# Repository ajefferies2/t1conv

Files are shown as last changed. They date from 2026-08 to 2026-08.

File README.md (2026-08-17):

# t1conv

Current Progress: Finished schematics, workinf on layout
100BASE-T1 ↔ 100BASE-TX media converter + dual CAN FD/USB adapter on one
board.

## Features

- Wire-speed T1↔TX conversion, PHY-to-PHY (DP83TC811 ↔ DP83822 over RGMII).
  No MAC, no firmware in the data path, converts with the MCU in reset.
- Two independent CAN FD channels over USB, using the gs_usb protocol:
  works out of the box with SocketCAN, python-can, and SavvyCAN.
- Software-switchable termination on each CAN channel (PhotoMOS; for example,
  `ip link set can0 type can termination 120`).
- Software-selectable T1 master/slave: FET on the strap pin, resampled by
  PHY reset. Boards are identical; role is a console command.
- Powered and flashed over USB-C. Blank MCU enumerates in DFU; BOOT button
  for recovery; SWD pads as last resort.

## Info

- Transformerless T1 MDI: TI-validated CMC, CM termination matched to that
  specific choke, 2 kV coupling network, 100 Ω differential on both MDI sides.
- Back-to-back RGMII delay budget: 25 MHz SDR at 100M, TX+RX internal delay
  strapped in the T1 PHY, strap tables derived from SNLA292/SNLU231.

## Schematics

The images below are exported from the current KiCad hierarchy.

### Top level

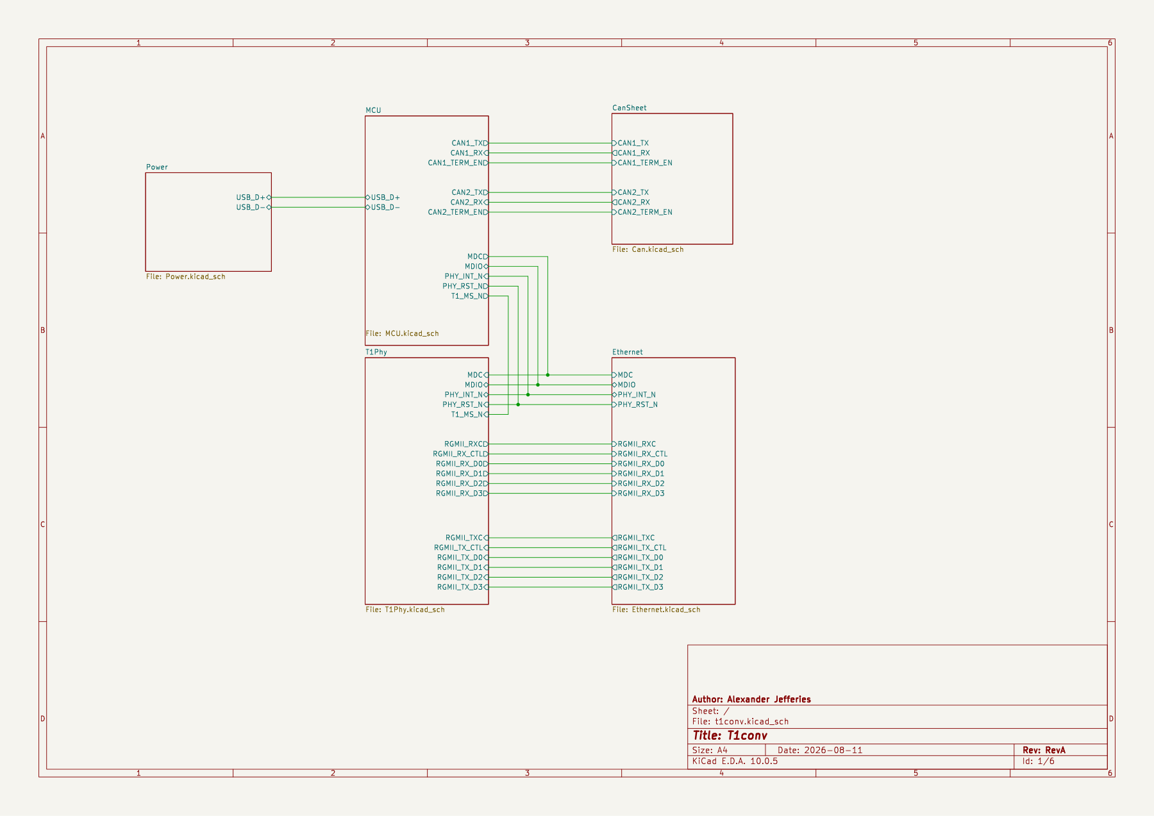
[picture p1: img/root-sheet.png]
Top-level schematic


### Power

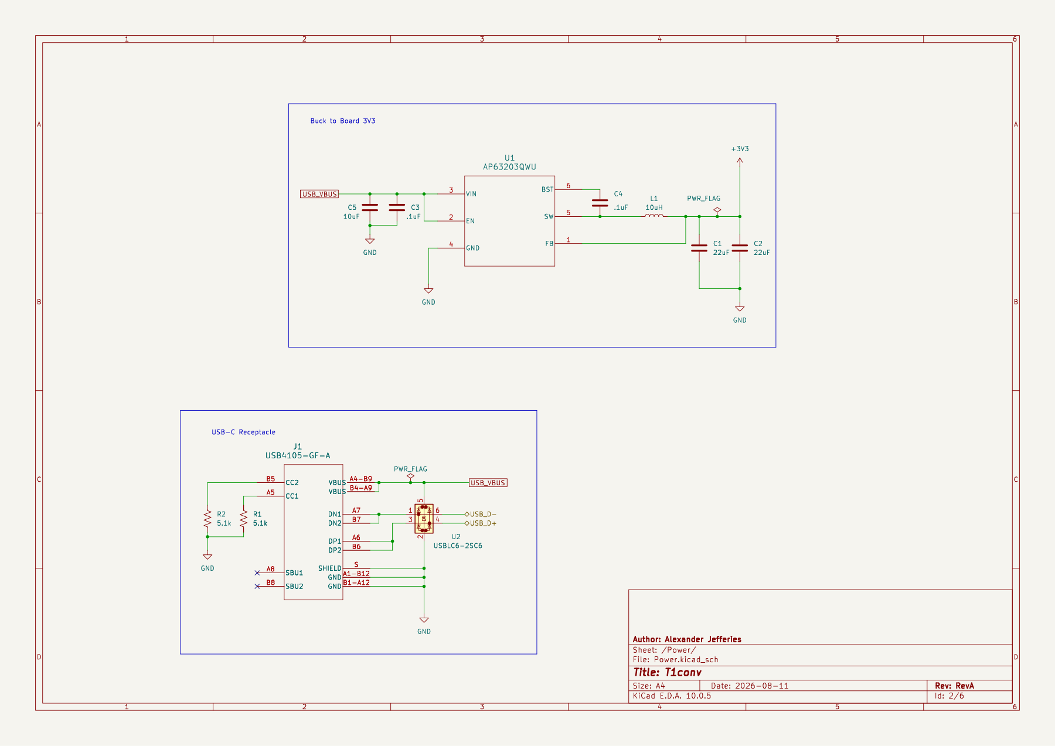
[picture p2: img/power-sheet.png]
Power schematic


### MCU

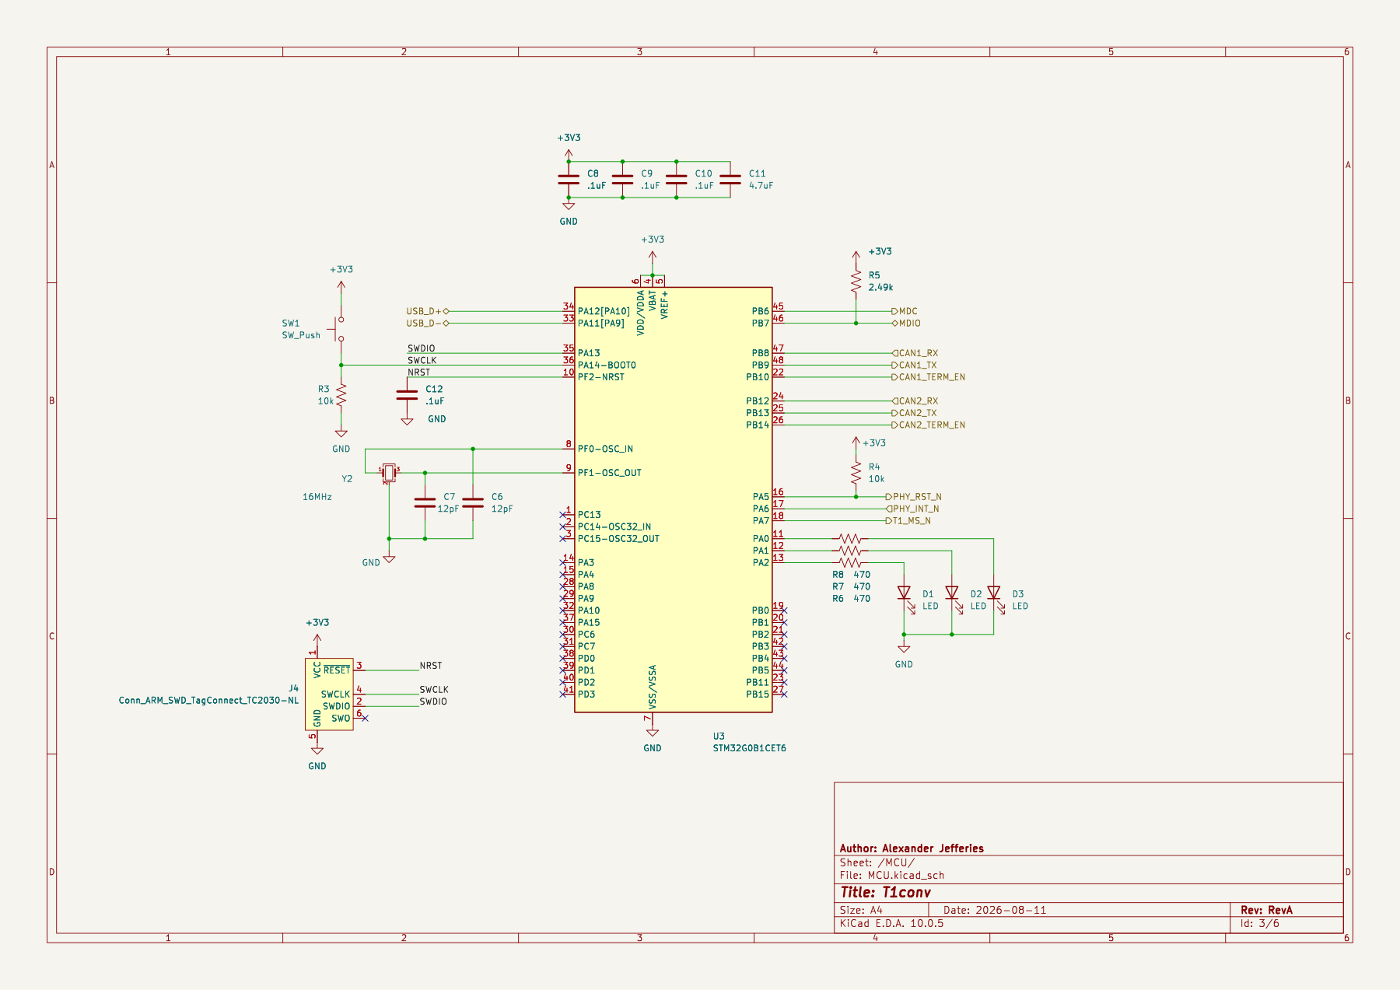
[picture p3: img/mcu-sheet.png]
MCU and USB schematic


### Dual CAN FD

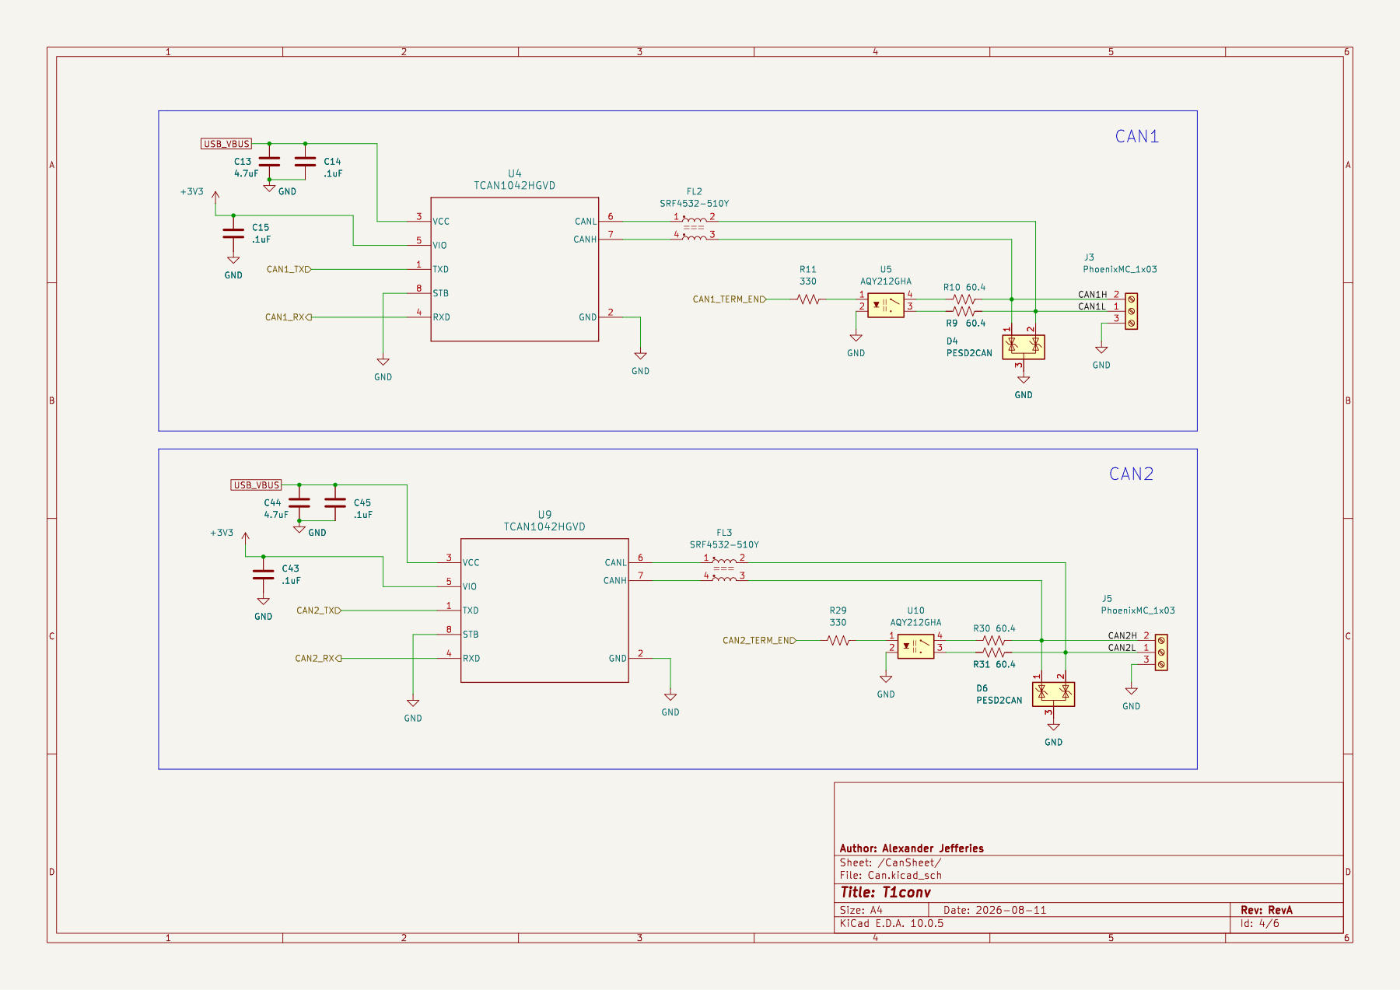
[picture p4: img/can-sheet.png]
Dual CAN FD schematic


### 100BASE-T1 PHY

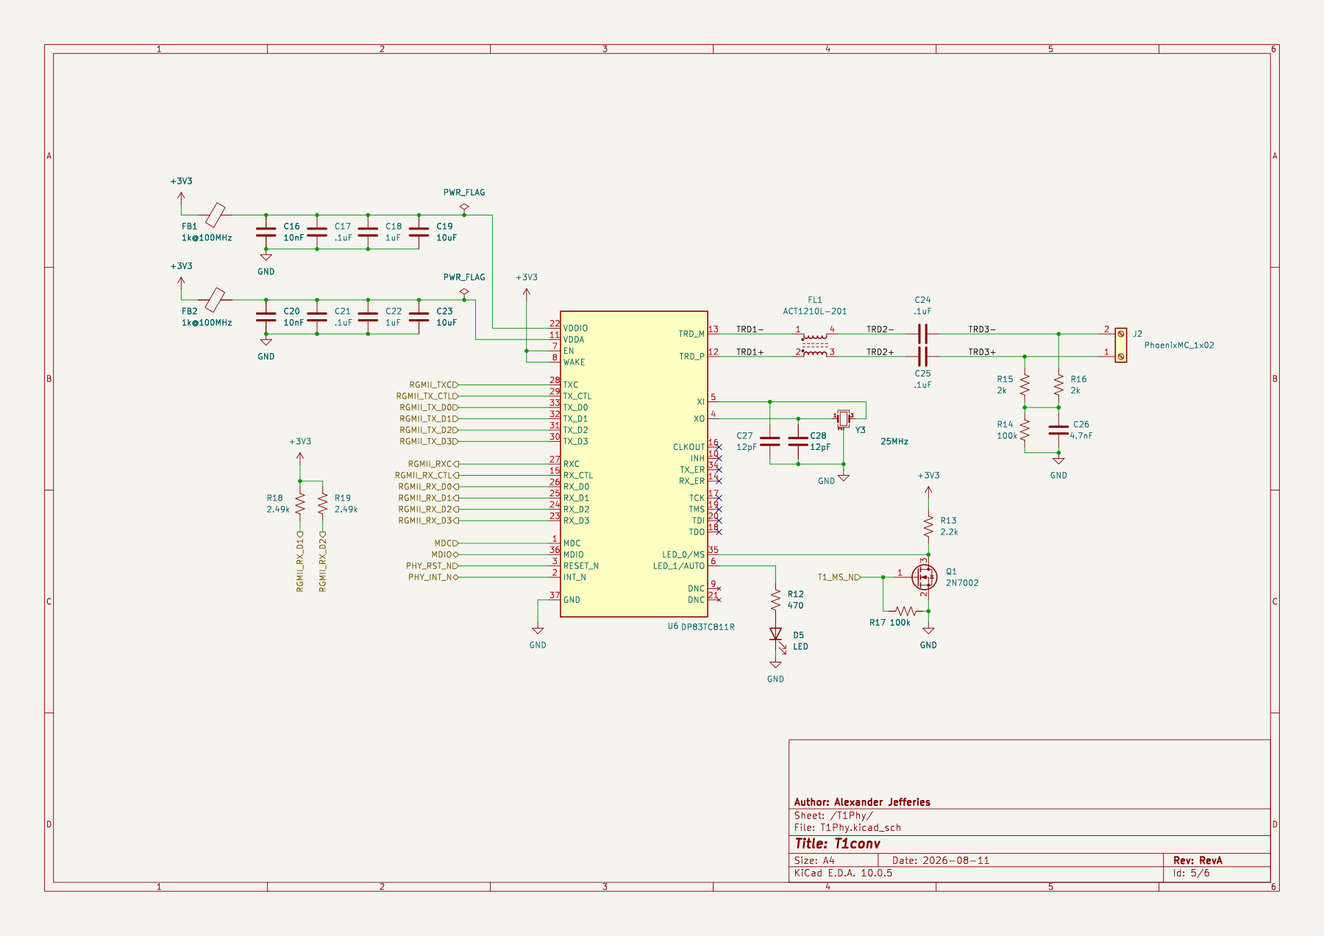
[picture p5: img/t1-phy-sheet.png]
100BASE-T1 PHY schematic


### 100BASE-TX Ethernet PHY

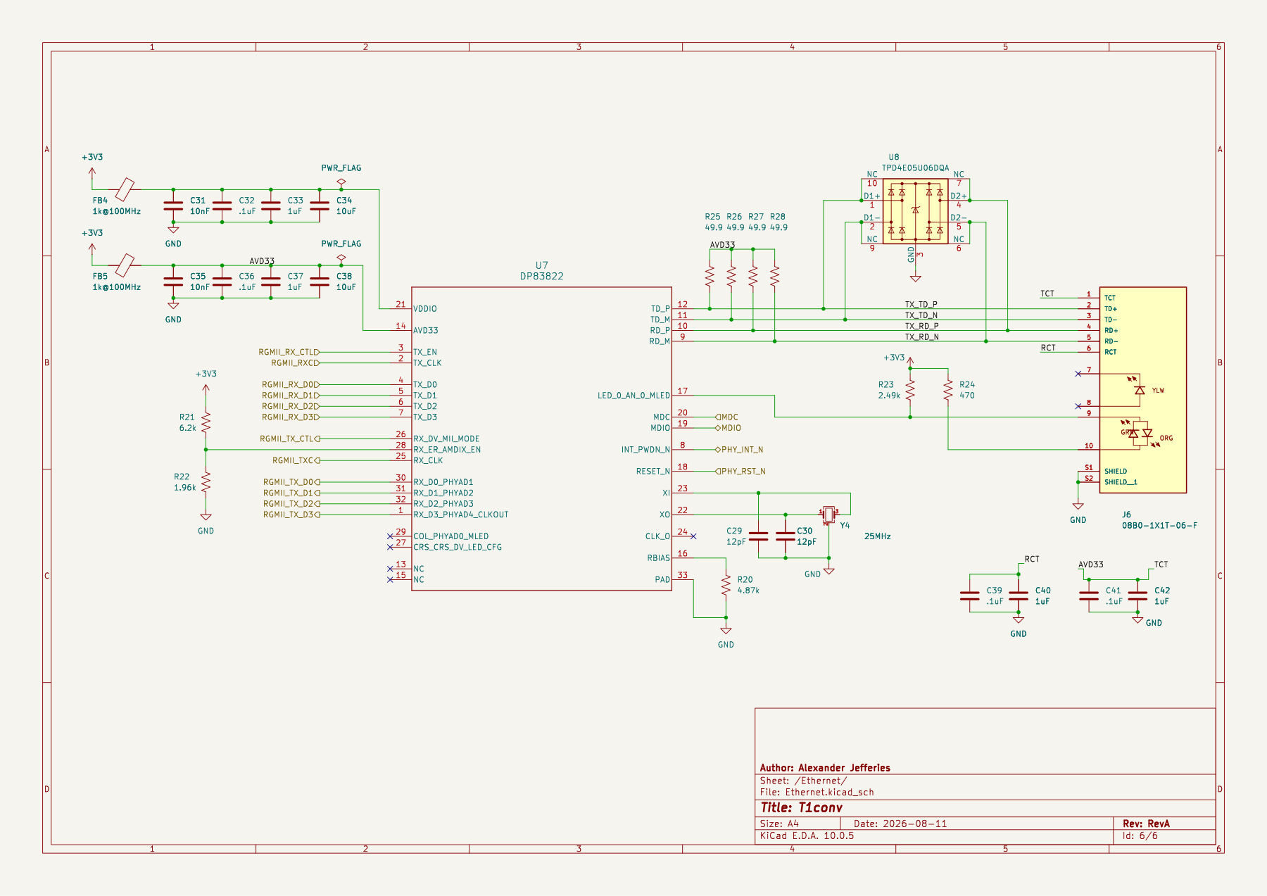
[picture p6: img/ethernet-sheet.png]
100BASE-TX Ethernet PHY schematic


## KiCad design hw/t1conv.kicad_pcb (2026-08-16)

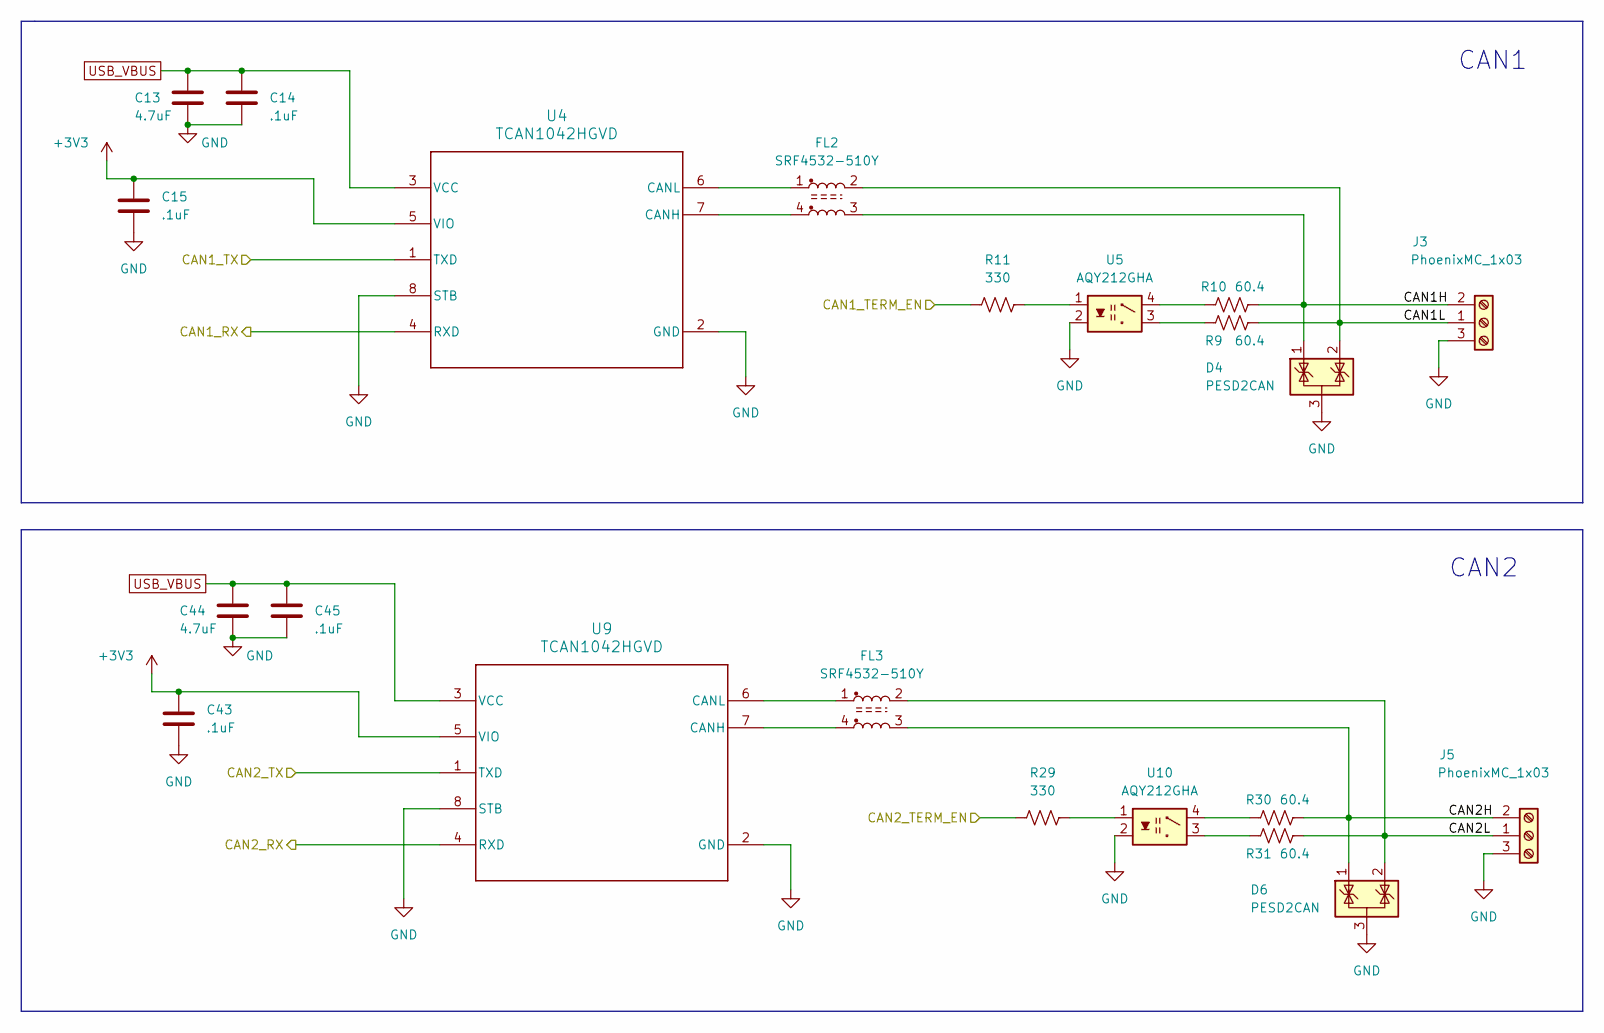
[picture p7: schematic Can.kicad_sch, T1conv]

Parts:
C13, C44: 4.7uF; C_0603_1608Metric
C14, C15, C43, C45: .1uF; C_0603_1608Metric
D4, D6: PESD2CAN; SOT-23; MPN PESD2CAN,215; DigiKey 1727-3891-1-ND
FL2, FL3: SRF4532-510Y; SRF4532; MPN SRF4532-510Y; LCSC C2651134
J3, J5: PhoenixMC_1x03; PhoenixContact_MC_1,5_3-G-3.5_1x03_P3.50mm_Horizontal; MPN 1803581
R9, R10, R30, R31: 60.4; R_0603_1608Metric
R11, R29: 330; R_0603_1608Metric
U4, U9: TCAN1042HGVD; TCAN1042_VSON8; MPN TCAN1042HGVD; DigiKey 296-TCAN1042HGVDR-ND
U5, U10: AQY212GHA; MPN AQY212GHAX; DigiKey 255-6063-1-ND

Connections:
+3V3: C15.1, C43.1, U4.5 (VIO), U9.5 (VIO); also elsewhere on the board
/CanSheet/CAN1H: D4.1 (K), FL2.3, J3.2, R10.2
/CanSheet/CAN1L: D4.2 (K), FL2.2, J3.1, R9.2
/CanSheet/CAN1_RX: U4.4 (RXD); also elsewhere on the board
/CanSheet/CAN1_TERM_EN: R11.2; also elsewhere on the board
/CanSheet/CAN1_TX: U4.1 (TXD); also elsewhere on the board
/CanSheet/CAN2H: D6.1 (K), FL3.3, J5.2, R30.2
/CanSheet/CAN2L: D6.2 (K), FL3.2, J5.1, R31.2
/CanSheet/CAN2_RX: U9.4 (RXD); also elsewhere on the board
/CanSheet/CAN2_TERM_EN: R29.2; also elsewhere on the board
/CanSheet/CAN2_TX: U9.1 (TXD); also elsewhere on the board
GND: C13.2, C14.2, C15.2, C43.2, C44.2, C45.2, D4.3 (A), D6.3 (A), J3.3, J5.3, U4.2 (GND), U4.8 (STB), U5.2, U9.2 (GND), U9.8 (STB), U10.2; also elsewhere on the board
unnamed: R9.1, U5.3
unnamed: R10.1, U5.4
unnamed: R11.1, U5.1
unnamed: R29.1, U10.1
unnamed: R30.1, U10.4
unnamed: R31.1, U10.3
unnamed: FL2.4, U4.7 (CANH)
unnamed: FL2.1, U4.6 (CANL)
unnamed: FL3.4, U9.7 (CANH)
unnamed: FL3.1, U9.6 (CANL)
USB_VBUS: C13.1, C14.1, C44.1, C45.1, U4.3 (VCC), U9.3 (VCC); also elsewhere on the board

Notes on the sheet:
CAN2
CAN1

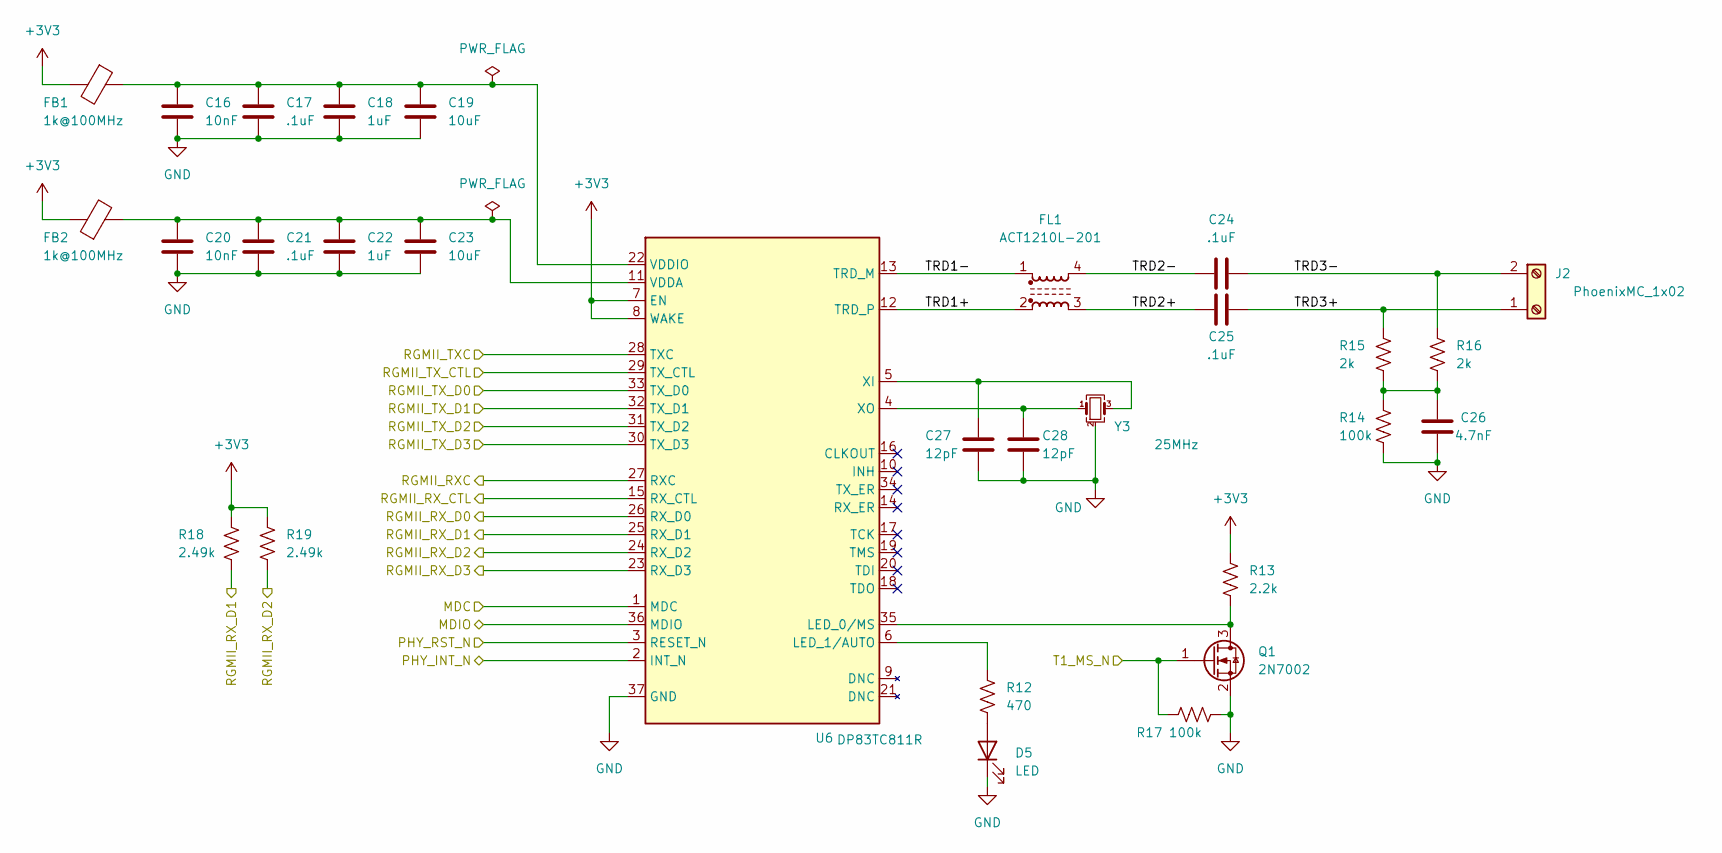
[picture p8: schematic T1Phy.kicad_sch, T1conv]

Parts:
C16, C20: 10nF; C_0603_1608Metric
C17, C21, C24, C25: .1uF; C_0603_1608Metric
C18, C22: 1uF; C_0603_1608Metric
C19, C23: 10uF; C_0603_1608Metric
C26: 4.7nF; C_0603_1608Metric
C27, C28: 12pF; C_0603_1608Metric
D5: LED; LED_0603_1608Metric
FB1, FB2: 1k@100MHz; R_0805_2012Metric; MPN house-brand basic tier - pick at sweep 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
FL1: ACT1210L-201; ACT1210L_3225; MPN ACT1210L-201-2P-TL00; DigiKey 445-ACT1210L-201-2P-TL00CT-ND
J2: PhoenixMC_1x02; PhoenixContact_MC_1,5_2-G-3.5_1x02_P3.50mm_Horizontal; MPN 1803578
Q1: 2N7002; SOT-23; MPN 2N7002; LCSC C8545
R12: 470; R_0603_1608Metric
R13: 2.2k; R_0603_1608Metric
R14, R17: 100k; R_0603_1608Metric
R15, R16: 2k; R_0603_1608Metric
R18, R19: 2.49k; R_0603_1608Metric
U6: DP83TC811R; DP83TC811R_RND0036A; MPN DP83TC811RWRNDRQ1; DigiKey 296-DP83TC811RWRNDRQ1-ND
Y3: 25MHz; Crystal_SMD_3225-4Pin_3.2x2.5mm

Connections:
+3V3: FB1.2, FB2.1, R13.1, R18.1, R19.1, U6.7 (EN), U6.8 (WAKE); also elsewhere on the board
/Ethernet/MDC: U6.1 (MDC); also elsewhere on the board
/Ethernet/MDIO: U6.36 (MDIO); also elsewhere on the board
/Ethernet/PHY_INT_N: U6.2 (INT_N); also elsewhere on the board
/Ethernet/PHY_RST_N: U6.3 (RESET_N); also elsewhere on the board
/Ethernet/RGMII_RXC: U6.27 (RXC); also elsewhere on the board
/Ethernet/RGMII_RX_CTL: U6.15 (RX_CTL); also elsewhere on the board
/Ethernet/RGMII_RX_D0: U6.26 (RX_D0); also elsewhere on the board
/Ethernet/RGMII_RX_D1: R18.2, U6.25 (RX_D1); also elsewhere on the board
/Ethernet/RGMII_RX_D2: R19.2, U6.24 (RX_D2); also elsewhere on the board
/Ethernet/RGMII_RX_D3: U6.23 (RX_D3); also elsewhere on the board
/Ethernet/RGMII_TXC: U6.28 (TXC); also elsewhere on the board
/Ethernet/RGMII_TX_CTL: U6.29 (TX_CTL); also elsewhere on the board
/Ethernet/RGMII_TX_D0: U6.33 (TX_D0); also elsewhere on the board
/Ethernet/RGMII_TX_D1: U6.32 (TX_D1); also elsewhere on the board
/Ethernet/RGMII_TX_D2: U6.31 (TX_D2); also elsewhere on the board
/Ethernet/RGMII_TX_D3: U6.30 (TX_D3); also elsewhere on the board
/MCU/T1_MS_N: Q1.1 (G), R17.1; also elsewhere on the board
/T1Phy/TRD1+: FL1.2, U6.12 (TRD_P)
/T1Phy/TRD1-: FL1.1, U6.13 (TRD_M)
/T1Phy/TRD2+: C25.2, FL1.3
/T1Phy/TRD2-: C24.1, FL1.4
/T1Phy/TRD3+: C25.1, J2.1, R15.1
/T1Phy/TRD3-: C24.2, J2.2, R16.1
GND: C16.2, C17.2, C18.2, C19.2, C20.2, C21.2, C22.2, C23.2, C26.2, C27.2, C28.2, D5.1 (K), Q1.2 (S), R14.2, R17.2, U6.37 (GND), Y3.2 (G), Y3.4 (G); also elsewhere on the board
unnamed: C26.1, R14.1, R15.2, R16.2
unnamed: D5.2 (A), R12.2
unnamed: Q1.3 (D), R13.2, U6.35 (LED_0/MS)
unnamed: R12.1, U6.6 (LED_1/AUTO)
unnamed: C20.1, C21.1, C22.1, C23.1, FB2.2, U6.11 (VDDA)
unnamed: C16.1, C17.1, C18.1, C19.1, FB1.1, U6.22 (VDDIO)
unnamed: C27.1, U6.5 (XI), Y3.3
unnamed: C28.1, U6.4 (XO), Y3.1

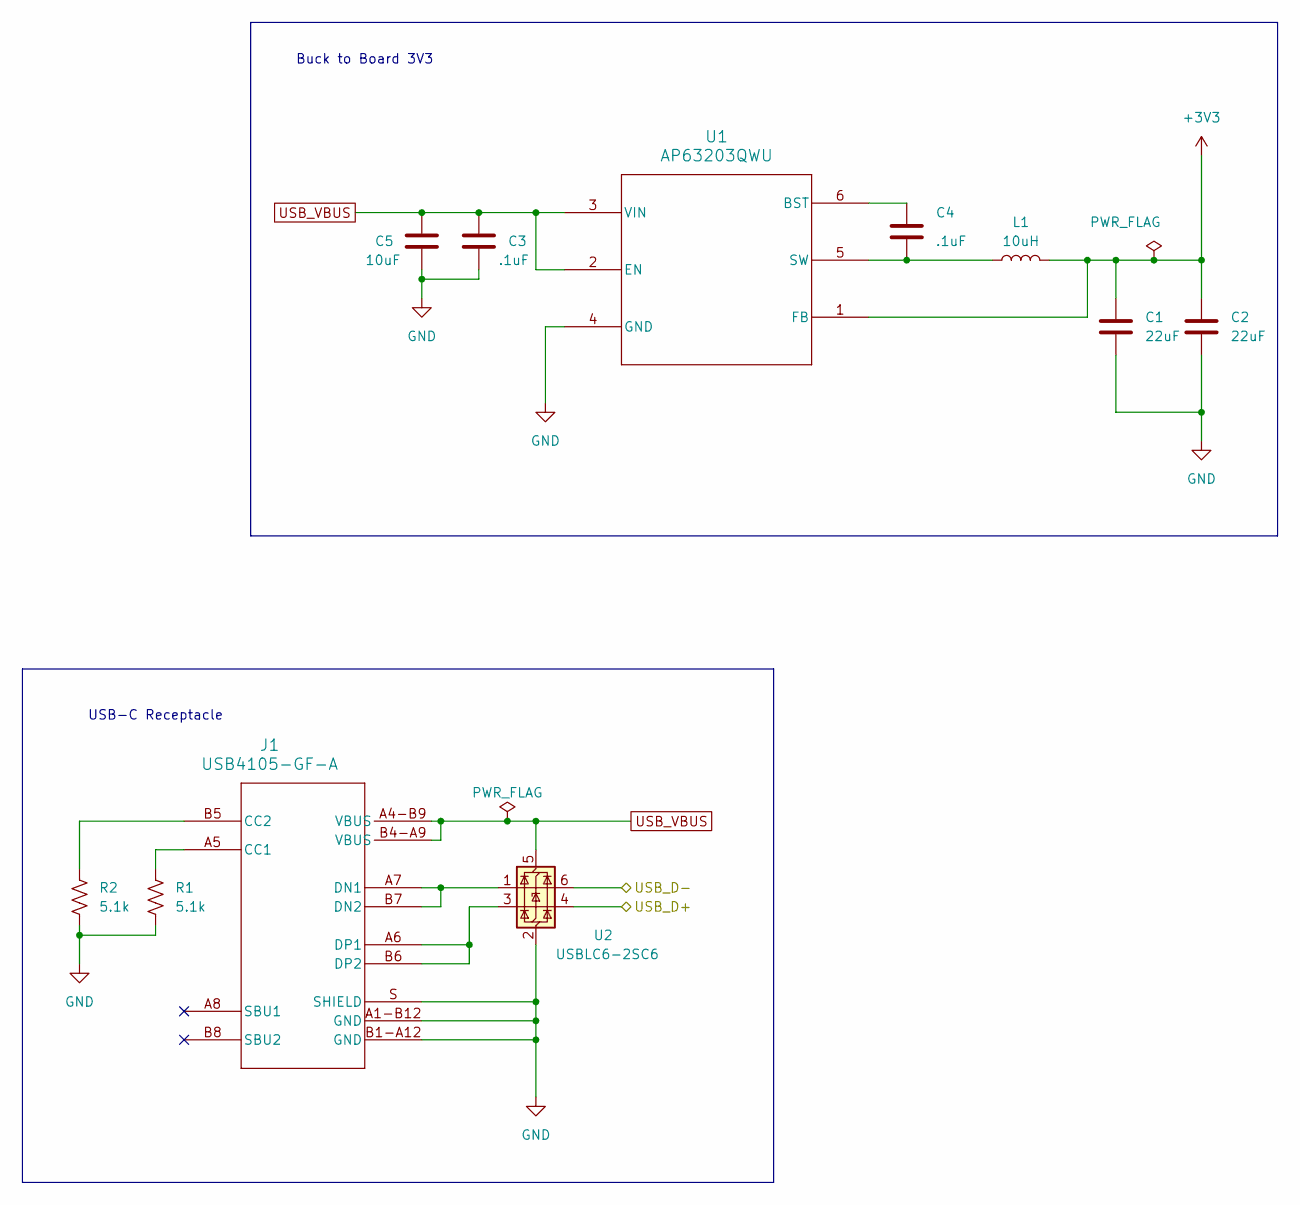
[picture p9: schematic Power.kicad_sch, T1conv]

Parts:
C1, C2: 22uF; C_0603_1608Metric
C3, C4: .1uF; C_0603_1608Metric
C5: 10uF; C_0603_1608Metric
J1: USB4105-GF-A; MPN USB4105-GF-A; DigiKey 2073-USB4105-GF-ACT-ND
L1: 10uH; SWPA5040
R1, R2: 5.1k; R_0603_1608Metric
U1: AP63203QWU; AP63203_TSOT26; MPN AP63203QWU-7; DigiKey AP63203QWU-7DICT-ND
U2: USBLC6-2SC6; SOT-23-6; MPN USBLC6-2SC6; DigiKey 497-5235-1-ND

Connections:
+3V3: C1.1, C2.1, L1.2, U1.1 (FB); also elsewhere on the board
/MCU/USB_D+: U2.4 (I/O2); also elsewhere on the board
/MCU/USB_D-: U2.6 (I/O1); also elsewhere on the board
GND: C1.2, C2.2, C3.2, C5.2, J1.A1-B12 (GND), J1.B1-A12 (GND), J1.S (SHIELD), R1.2, R2.2, U1.4 (GND), U2.2 (GND); also elsewhere on the board
unnamed: J1.A5 (CC1), R1.1
unnamed: J1.B5 (CC2), R2.1
unnamed: J1.A7 (DN1), J1.B7 (DN2), U2.1 (I/O1)
unnamed: J1.A6 (DP1), J1.B6 (DP2), U2.3 (I/O2)
unnamed: C4.1, U1.6 (BST)
unnamed: C4.2, L1.1, U1.5 (SW)
USB_VBUS: C3.1, C5.1, J1.A4-B9 (VBUS), J1.B4-A9 (VBUS), U1.2 (EN), U1.3 (VIN), U2.5 (VBUS); also elsewhere on the board

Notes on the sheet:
USB-C Receptacle
Buck to Board 3V3

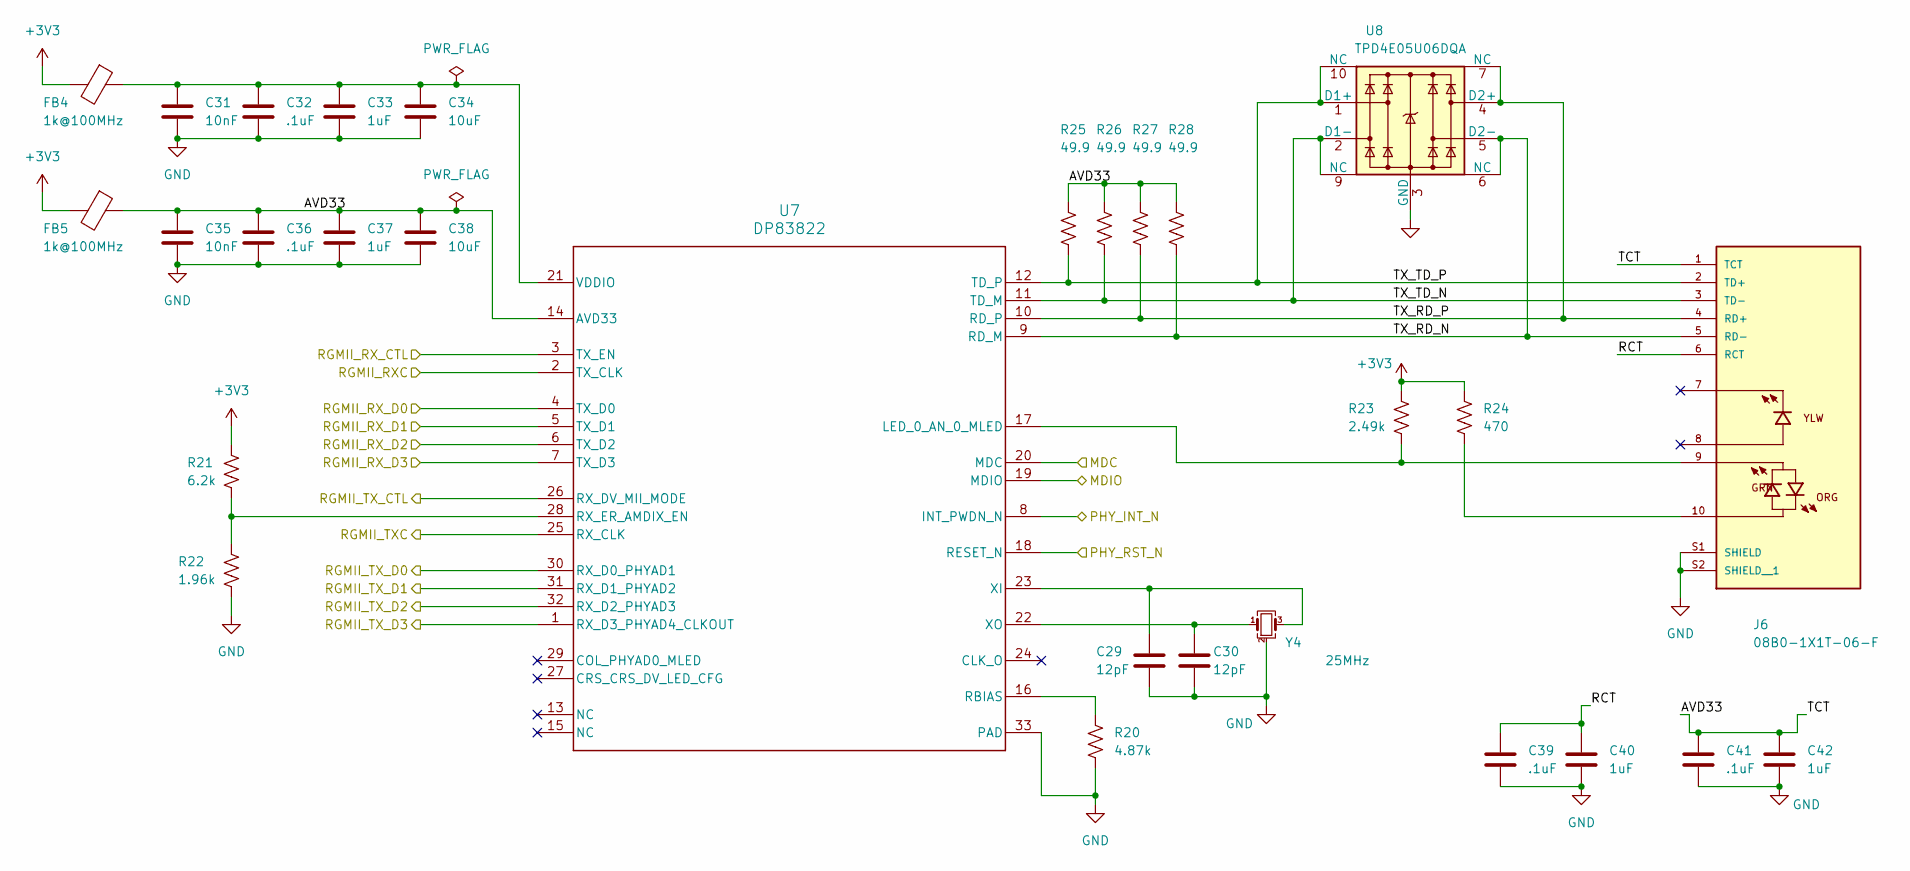
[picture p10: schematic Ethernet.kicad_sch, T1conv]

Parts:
C29, C30: 12pF; C_0603_1608Metric
C31, C35: 10nF; C_0603_1608Metric
C32, C36, C39, C41: .1uF; C_0603_1608Metric
C33, C37, C40, C42: 1uF; C_0603_1608Metric
C34, C38: 10uF; C_0603_1608Metric
FB4, FB5: 1k@100MHz; R_0805_2012Metric; MPN house-brand basic tier - pick at sweep 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
J6: 08B0-1X1T-06-F; MPN 08B0-1X1T-06-F; DigiKey 507-1445-ND
R20: 4.87k; R_0603_1608Metric
R21: 6.2k; R_0603_1608Metric
R22: 1.96k; R_0603_1608Metric
R23: 2.49k; R_0603_1608Metric
R24: 470; R_0603_1608Metric
R25, R26, R27, R28: 49.9; R_0603_1608Metric
U7: DP83822; DP83822_RHB0032B; MPN DP83822IRHBR; DigiKey 296-DP83822IRHBRCT-ND
U8: TPD4E05U06DQA; TPD4E05U06_DQA0010A; MPN TPD4E05U06DQAR; DigiKey 296-35765-1-ND
Y4: 25MHz; Crystal_SMD_3225-4Pin_3.2x2.5mm

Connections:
+3V3: FB4.2, FB5.2, R21.1, R23.1, R24.1; also elsewhere on the board
/Ethernet/AVD33: C35.1, C36.1, C37.1, C38.1, C41.1, C42.1, FB5.1, J6.1 (TCT), R25.1, R26.1, R27.1, R28.1, U7.14 (AVD33)
/Ethernet/MDC: U7.20 (MDC); also elsewhere on the board
/Ethernet/MDIO: U7.19 (MDIO); also elsewhere on the board
/Ethernet/PHY_INT_N: U7.8 (INT_PWDN_N); also elsewhere on the board
/Ethernet/PHY_RST_N: U7.18 (RESET_N); also elsewhere on the board
/Ethernet/RCT: C39.1, C40.1, J6.6 (RCT)
/Ethernet/RGMII_RXC: U7.2 (TX_CLK); also elsewhere on the board
/Ethernet/RGMII_RX_CTL: U7.3 (TX_EN); also elsewhere on the board
/Ethernet/RGMII_RX_D0: U7.4 (TX_D0); also elsewhere on the board
/Ethernet/RGMII_RX_D1: U7.5 (TX_D1); also elsewhere on the board
/Ethernet/RGMII_RX_D2: U7.6 (TX_D2); also elsewhere on the board
/Ethernet/RGMII_RX_D3: U7.7 (TX_D3); also elsewhere on the board
/Ethernet/RGMII_TXC: U7.25 (RX_CLK); also elsewhere on the board
/Ethernet/RGMII_TX_CTL: U7.26 (RX_DV_MII_MODE); also elsewhere on the board
/Ethernet/RGMII_TX_D0: U7.30 (RX_D0_PHYAD1); also elsewhere on the board
/Ethernet/RGMII_TX_D1: U7.31 (RX_D1_PHYAD2); also elsewhere on the board
/Ethernet/RGMII_TX_D2: U7.32 (RX_D2_PHYAD3); also elsewhere on the board
/Ethernet/RGMII_TX_D3: U7.1 (RX_D3_PHYAD4_CLKOUT); also elsewhere on the board
/Ethernet/TX_RD_N: J6.5 (RD-), R28.2, U7.9 (RD_M), U8.5 (D2-), U8.6 (NC)
/Ethernet/TX_RD_P: J6.4 (RD+), R27.2, U7.10 (RD_P), U8.4 (D2+), U8.7 (NC)
/Ethernet/TX_TD_N: J6.3 (TD-), R26.2, U7.11 (TD_M), U8.2 (D1-), U8.9 (NC)
/Ethernet/TX_TD_P: J6.2 (TD+), R25.2, U7.12 (TD_P), U8.1 (D1+), U8.10 (NC)
GND: C29.2, C30.2, C31.2, C32.2, C33.2, C34.2, C35.2, C36.2, C37.2, C38.2, C39.2, C40.2, C41.2, C42.2, J6.S1 (SHIELD), J6.S2 (SHIELD__1), R20.2, R22.2, U7.33 (PAD), U8.3 (GND), U8.8 (GND), Y4.2 (G), Y4.4 (G); also elsewhere on the board
unnamed: J6.10, R24.2
unnamed: J6.9, R23.2, U7.17 (LED_0_AN_0_MLED)
unnamed: R20.1, U7.16 (RBIAS)
unnamed: R21.2, R22.1, U7.28 (RX_ER_AMDIX_EN)
unnamed: C31.1, C32.1, C33.1, C34.1, FB4.1, U7.21 (VDDIO)
unnamed: C29.1, U7.23 (XI), Y4.3
unnamed: C30.1, U7.22 (XO), Y4.1

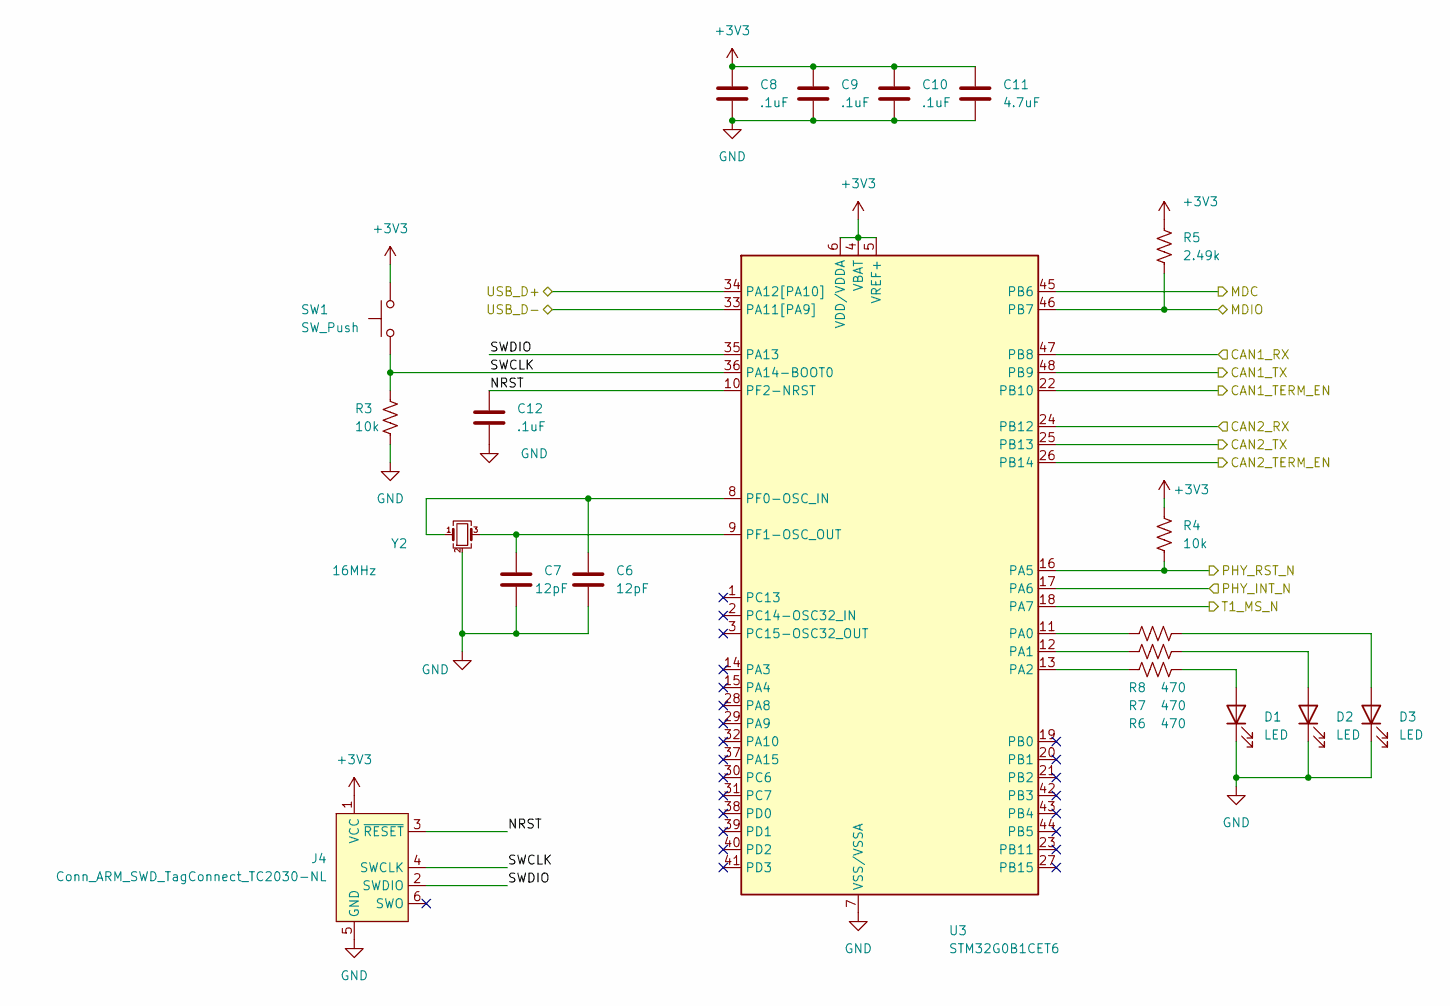
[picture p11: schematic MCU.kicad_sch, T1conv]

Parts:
C6, C7: 12pF; C_0603_1608Metric
C8, C9, C10, C12: .1uF; C_0603_1608Metric
C11: 4.7uF; C_0603_1608Metric
D1, D2, D3: LED; LED_0603_1608Metric
J4: Conn_ARM_SWD_TagConnect_TC2030-NL; Tag-Connect_TC2030-IDC-NL_2x03_P1.27mm_Vertical
R3, R4: 10k; R_0603_1608Metric
R5: 2.49k; R_0603_1608Metric
R6, R7, R8: 470; R_0603_1608Metric
SW1: SW_Push; SW_Push_Panasonic_EVQP4_EdgeMount
U3: STM32G0B1CET6; STM32G0B1_LQFP48; MPN STM32G0B1CET6; DigiKey 497-STM32G0B1CET6-ND
Y2: 16MHz; Crystal_SMD_3225-4Pin_3.2x2.5mm

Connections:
+3V3: C8.1, C9.1, C10.1, C11.1, J4.1 (VCC), R4.1, R5.1, SW1.2, U3.4 (VBAT), U3.5 (VREF+), U3.6 (VDD/VDDA); also elsewhere on the board
/CanSheet/CAN1_RX: U3.47 (PB8); also elsewhere on the board
/CanSheet/CAN1_TERM_EN: U3.22 (PB10); also elsewhere on the board
/CanSheet/CAN1_TX: U3.48 (PB9); also elsewhere on the board
/CanSheet/CAN2_RX: U3.24 (PB12); also elsewhere on the board
/CanSheet/CAN2_TERM_EN: U3.26 (PB14); also elsewhere on the board
/CanSheet/CAN2_TX: U3.25 (PB13); also elsewhere on the board
/Ethernet/MDC: U3.45 (PB6); also elsewhere on the board
/Ethernet/MDIO: R5.2, U3.46 (PB7); also elsewhere on the board
/Ethernet/PHY_INT_N: U3.17 (PA6); also elsewhere on the board
/Ethernet/PHY_RST_N: R4.2, U3.16 (PA5); also elsewhere on the board
/MCU/NRST: C12.1, J4.3 (~RESET), U3.10 (PF2-NRST)
/MCU/SWCLK: J4.4 (SWCLK), R3.1, SW1.1, U3.36 (PA14-BOOT0)
/MCU/SWDIO: J4.2 (SWDIO), U3.35 (PA13)
/MCU/T1_MS_N: U3.18 (PA7); also elsewhere on the board
/MCU/USB_D+: U3.34 (PA12[PA10]); also elsewhere on the board
/MCU/USB_D-: U3.33 (PA11[PA9]); also elsewhere on the board
GND: C6.2, C7.2, C8.2, C9.2, C10.2, C11.2, C12.2, D1.1 (K), D2.1 (K), D3.1 (K), J4.5 (GND), R3.2, U3.7 (VSS/VSSA), Y2.2 (G), Y2.4 (G); also elsewhere on the board
unnamed: D1.2 (A), R6.2
unnamed: D2.2 (A), R7.2
unnamed: D3.2 (A), R8.2
unnamed: R8.1, U3.11 (PA0)
unnamed: R7.1, U3.12 (PA1)
unnamed: R6.1, U3.13 (PA2)
unnamed: C6.1, U3.8 (PF0-OSC_IN), Y2.1
unnamed: C7.1, U3.9 (PF1-OSC_OUT), Y2.3

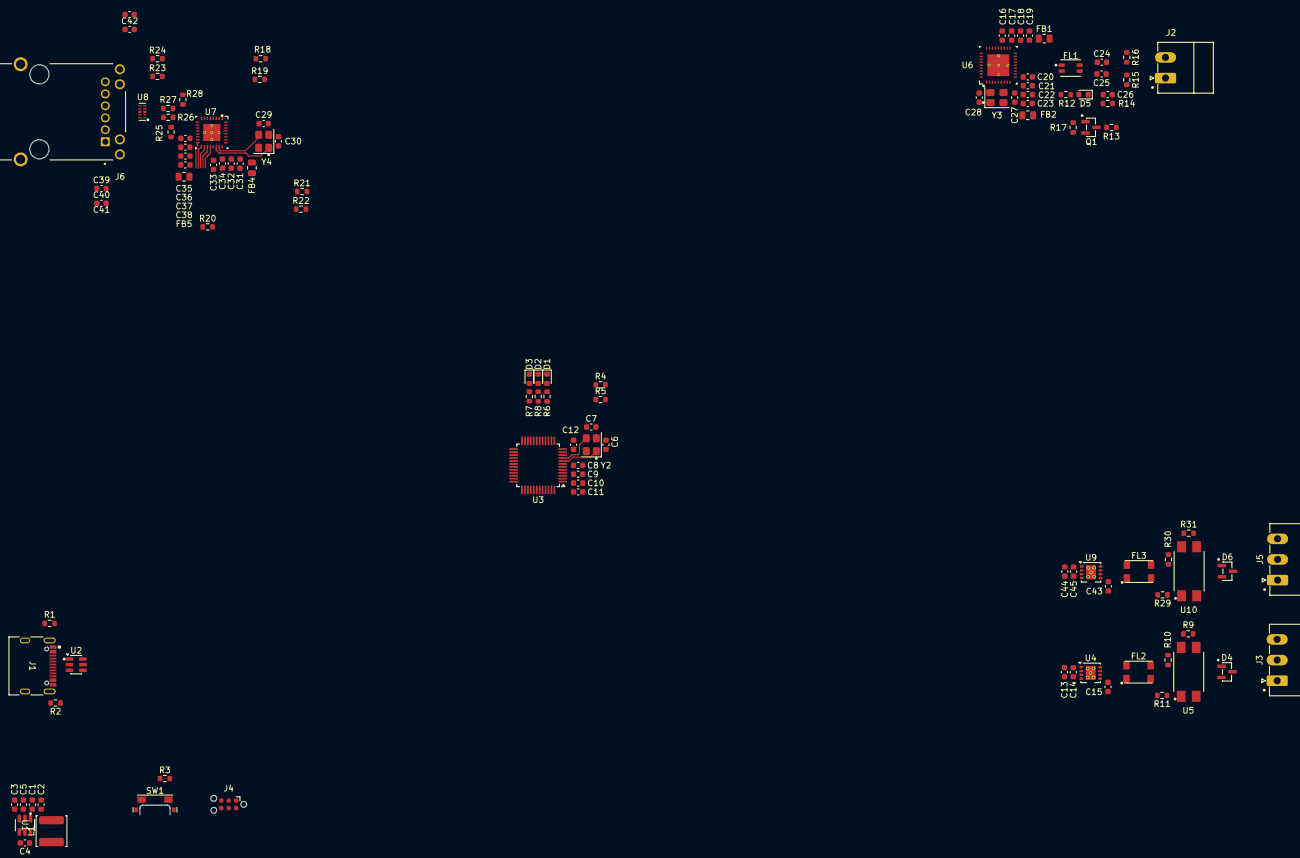
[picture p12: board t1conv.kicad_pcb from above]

Board: 4 copper layers, 111 parts (0 on the bottom side), 86 nets.
